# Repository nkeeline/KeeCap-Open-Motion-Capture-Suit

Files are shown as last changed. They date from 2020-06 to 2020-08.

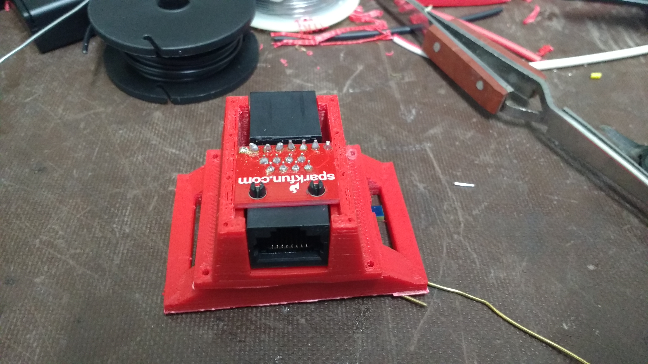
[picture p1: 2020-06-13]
Build Procedures/Sensor Build 2.jpg

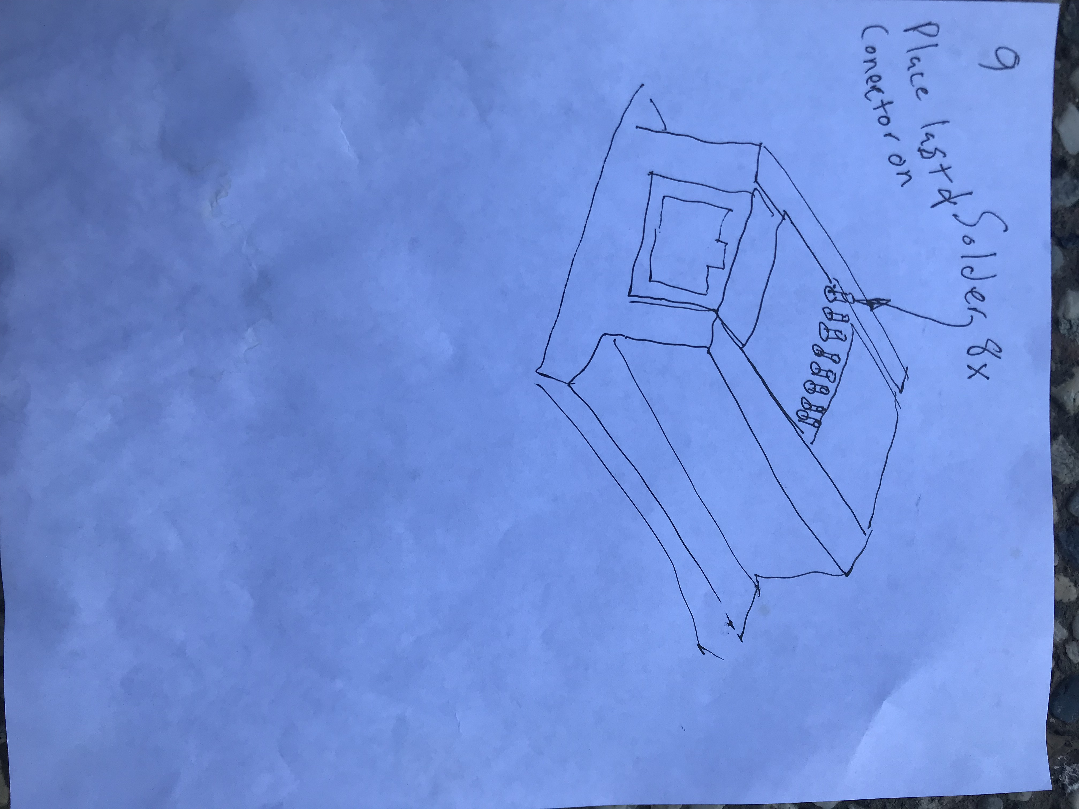
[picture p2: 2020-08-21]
Build Procedures/IMG_2739.JPG

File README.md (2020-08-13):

# KeeCap-Open-Motion-Capture-Suit
This is an arduino based open motion capture suit and all files necessary to build it.

If you are interested in this suit please watch these video tutorials:
Tutorial on how to use this code:

https://youtu.be/FGNmMZX0g_M

Tutorial on how the suit talks to Blender:

https://youtu.be/CypV9pPTCXo

If you want to test the PC only side without a suit you can use the latest python script from blender python dir in blender 2.83 and open the Move rig tester from the blender dir.

For the script to work in blender you MUST install PySerial into blender watch the second tutorial above to see how.

# This folder...

The suit bom.ods in the root contains all part numbers and prices for the components to buy the suit.  Open the file in libre office calc.  Most of the parts listed are from digikey.com, for example the imu board is this:
https://www.digikey.com/product-detail/en/microchip-technology/ATBNO055-XPRO/ATBNO055-XPRO-ND/5230918

# Arduino Code

This directory contains all of the code to put on the Arduino Mega 2560 in the suit.  It also contains the libraries the code uses you will need to place in your aruino libraries folder for the .ino file to compile.

# Blender Files

This contains the blender 2.83 files to export stl files necessary to 3d print the suit and a Move Rig.blend file with a character in it to map the motion captures to.

# Blender Python 

Contains a copy of the .py files for the addon to run in blender to import files from the suit.

# Build Procedures

This is the work instructions step by step for building the suit.

# Captures

Here are some sample captures taken during development and on set with sample videos of the capture process.

# Schematics Diagrams

These are the fritzing schematics and diagrams for the wiring of the suite to get an overview of how it's wired.

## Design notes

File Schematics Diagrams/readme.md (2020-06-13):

This folder contains all of the schematics and diagrams for building the suit

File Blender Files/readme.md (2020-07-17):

# Move Rig.blend
open this file and use it with the python script to apply poses to the rig in the blend file.  The sensors on the rig can be tweaked prior to applying a pose to adjust for off kilter sensors during the acquisition.

# You must install PySerial into blender python for the scripts to work!
for instructions on how to install it watch this tutorial:
https://www.youtube.com/watch?v=CypV9pPTCXo

# Waist and Arfuino and Accel Case blend files
These files contain all of the 3d printable models to create the suit.

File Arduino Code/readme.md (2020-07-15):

This folder contains all of the arduino code for putting in the arduino for the motion capture suit.

Unpack the MotionCaptureArduinoLibraries.zip into your Arduino Libraries folder.  then open the INO file and upload it into your Arduino Mega.

# Ignore Everything Below!!!! I tried to install all these from the web recently and the current libraries are no longer compatible with the code!!!  I packed up the libraries that work into a zip and included it in the repo so future generations will always be able to build the code.

To run the above code you need to put the following libraries into your arduino environment:

# Adafruit Unified BNO055 Driver (AHRS/Orientation) #

https://github.com/adafruit/Adafruit_Sensor

download the files from the above link and unpack the Adafruit_Sensor-Master folder into your Arduino/libraries folder.  Delete the -master from the folder name.

https://github.com/adafruit/Adafruit_BNO055

download the files from the above link and unpack the Adafruit_Sensor-Master folder into your Arduino/libraries folder.  Delete the -master from the folder name.

# Adafruit Data logging shield

for more information on the shield view this: https://learn.adafruit.com/adafruit-data-logger-shield/overview

use the above link to install the sd card and real time clock libraries, but in short download this:
https://github.com/adafruit/SD/archive/master.zip

download the files from the above link and unpack the SD-Master folder into your Arduino/libraries folder.  Delete the -master from the folder name.

also download this:

https://github.com/adafruit/RTClib

download the files from the above link and unpack the RTClib-Master folder into your Arduino/libraries folder.  Delete the -master from the folder name.

# Liquid Menu and LIquid Crystal from here:
https://github.com/arduino-libraries/LiquidCrystal
download the files from the above link and unpack the LiquidCrystal-Master folder into your Arduino/libraries folder.  Delete the -master from the folder name.

download the files from the above link and unpack the LiquidCristal-Master folder into your Arduino/libraries folder.  Delete the -master from the folder name.

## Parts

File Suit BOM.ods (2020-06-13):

Index | Quantity | Part Number | Description | Customer Reference | Available Quantity | Backorder Quantity | Unit Price USD | Extended Price USD
Chest BOM
1 | 1 | 1050-1018-ND | BOARD MCU MEGA2560 |  | 1 | 0 | $38.50 | $38.50
2 | 2 | ATBNO055-XPRO-ND | BNO055 XPLAINED PRO EVAL KIT |  | 1 | 0 | $21.43 | $21.43
3 | 1 | 1528-1044-ND | ASSEMBLED DATA LOGGING SHIELD |  | 1 | 0 | $13.95 | $13.95
4 | 2 | 1528-1363-ND | TCA9548A I2C MULTIPLEXER BOARD |  | 1 | 0 | $6.95 | $6.95
5 | 10 | 1568-1097-ND | RJ45 BREAKOUT |  | 4 | 0 | $0.95 | $3.80
6 | 10 | 609-1046-ND | CONN MOD JACK 8P8C R/A UNSHLD |  | 4 | 0 | $0.56 | $2.25
7 | 4 | EG2015-ND | SWITCH PUSH SPST-NO 3A 125V |  | 1 | 0 | $1.21 | $1.21
8 |  | EG2011-ND | SWITCH PUSH SPST-NO 3A 125V |  | 1 |  | $1.21 | $1.21
9 |  | amazon:https://www.amazon.com/dp/B071XP6PPT/ref=sspa_dk_detail_2?psc=1 | FICBOX IIC/I2C 1602 Serial 5V Blue Backlight LCD Display For Arduino 2560 UNO AVR |  | 1 |  | $9.99 | $9.99
Waist BOM
1 | 2 | 1528-1363-ND | TCA9548A I2C MULTIPLEXER BOARD |  | 1 | 0 | $6.95 | $6.95
2 | 10 | 1568-1097-ND | RJ45 BREAKOUT |  | 3 | 0 | $0.95 | $2.85
3 | 10 | 609-1046-ND | CONN MOD JACK 8P8C R/A UNSHLD |  | 3 | 0 | $0.56 | $1.69
4 | 2 | ATBNO055-XPRO-ND | BNO055 XPLAINED PRO EVAL KIT |  | 1 | 0 | $21.43 | $21.43
5 |  | 1528-1430-ND | BREAKOUT BOARD LM3671 3.3V |  | 1 | 0 | $4.95 | $4.95
Full Suit Sensors BOM
1 | 10 | 1568-1097-ND | RJ45 BREAKOUT |  | 20 | 0 | $0.95 | $19.00
2 | 10 | 609-1046-ND | CONN MOD JACK 8P8C R/A UNSHLD |  | 20 | 0 | $0.56 | $11.26
3 | 2 | ATBNO055-XPRO-ND | BNO055 XPLAINED PRO EVAL KIT |  | 13 | 0 | $21.43 | $278.59
 |  |  |  |  |  |  | total: | $446.01
6 | 1 | 1568-1357-ND | HOOK-UP WIRE ASSORT SOLID 22AWG |  |  | 0 | $16.95 | $16.95
 |  | https://www.amazon.com/IWISS-Terminal-Ratchet-AWG28-18-0-1-1-0MM%C2%B2/dp/B017JU20Z6?s=aps
 |  | https://www.amazon.com/QLOUNI-Housing-Connector-Adaptor-Assortment/dp/B0774NMT1S
5 |  | 1528-1430-ND | BREAKOUT BOARD LM3671 3.3V |  | 1 | 0 | $4.95 | $4.95
1 | 2 | 1528-1363-ND | TCA9548A I2C MULTIPLEXER BOARD |  | 1 | 0 | $6.95 | $6.95
 |  | 1568-1358-ND | HOOK-UP WIRE ASSORT STRAND 22AWG |  | 1 |  | $16.95 | $16.95
 |  | 1568-1357-ND | HOOK-UP WIRE ASSORT SOLID 22AWG |  | 1 |  | $16.95 | $16.95

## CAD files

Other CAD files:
Blender Files/Accel Case 2nd try.blend

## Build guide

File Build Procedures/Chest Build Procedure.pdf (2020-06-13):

### Chest Build Procedure

### Names of Boards refer to this page to get the

names of the components.

Mega 2560 (the brain)

Adafruit I2C multiplexer
board.

IMU (inertial
measurement Unit)

Adafruitt Data Logging
Shield (SD card board)

### During build make sure all solder joints connect the pin to the hole (no gold rings showing). Hold the iron for a second or two on the pin to let the solder wick into the shaft with the pin in it)

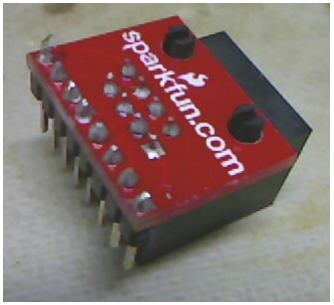
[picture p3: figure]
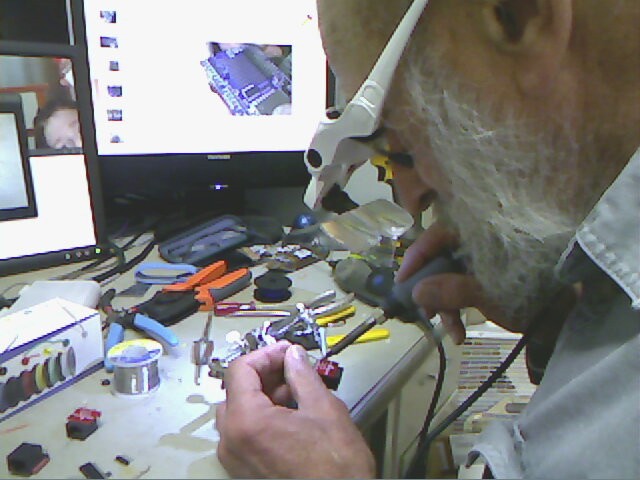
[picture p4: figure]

Print Out Chest Base

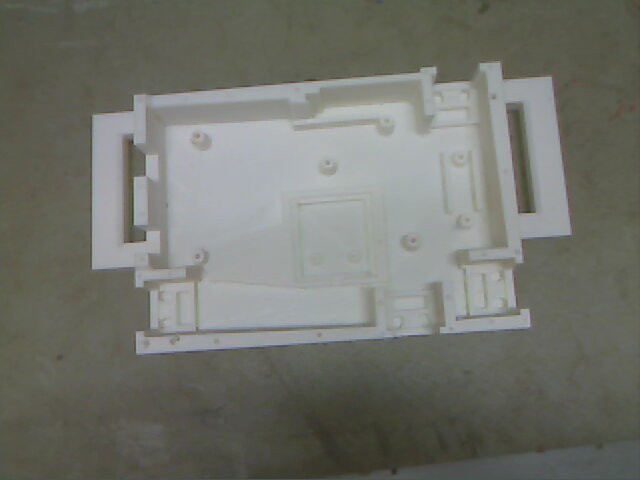
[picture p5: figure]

Don’t forget the
female header
on the center
pins.

Install all headers necessary to solder to the Adafruit Data Logging (sd card) shield into the Mega 2560 board.

Add the shield on to the 2560 and solder all of the headers in.

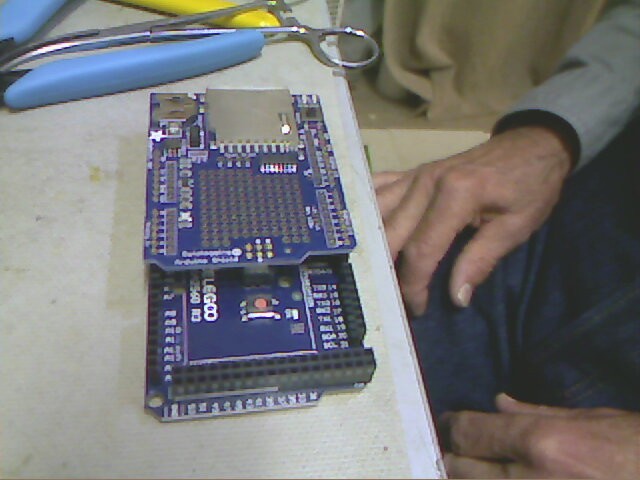
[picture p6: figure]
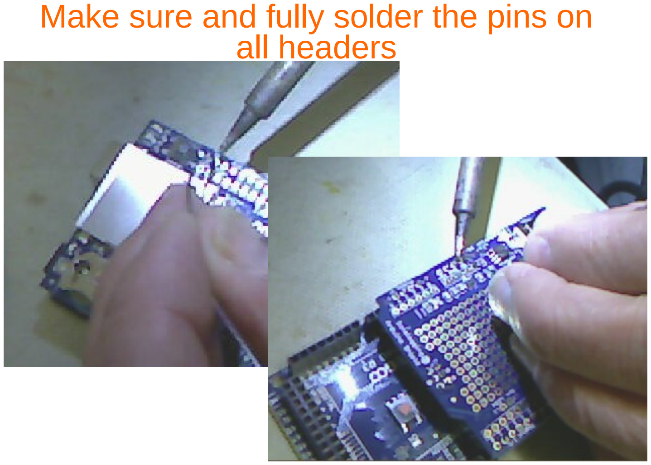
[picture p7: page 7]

Make sure and fully solder the pins on all headers

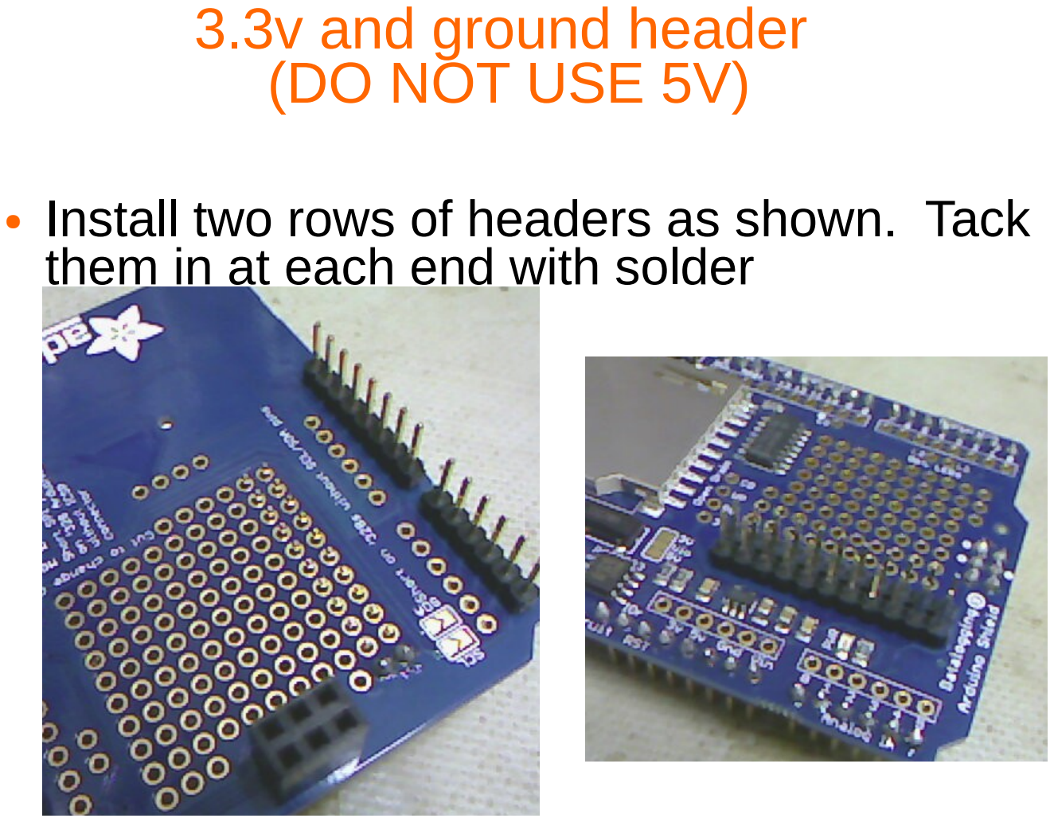
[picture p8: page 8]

3.3v and ground header
(DO NOT USE 5V)
- Install two rows of headers as shown. Tack them in at each end with solder

Solder a Red Wire up through the 3V hole and connect it to the row of header that is closest to the center of the board.

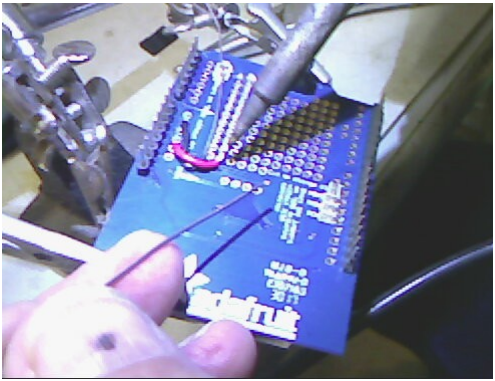
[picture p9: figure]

Connect a black wire through the Gnd hole and connect it to the row of pins closest to the edge

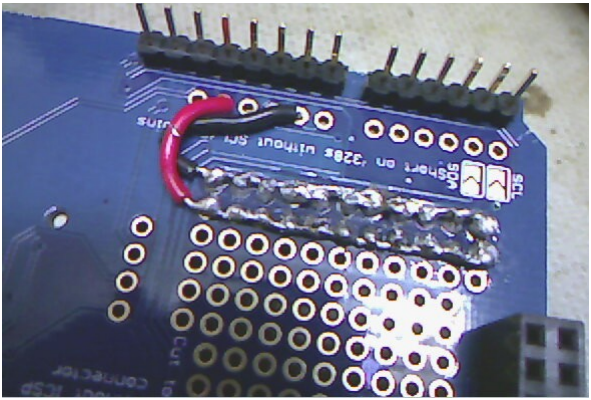
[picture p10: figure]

This is what the header looks like when done.

Solder a Header on pins 0-5 and Solder a wire on the topside from L1 to pin 6 on the Data Logging shield

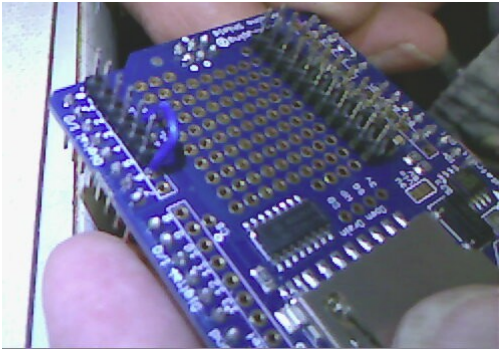
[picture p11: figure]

Put header on pins Sclk through 8 and Solder a wire on the topside from L2 to pin 7 on the Data Logging shield

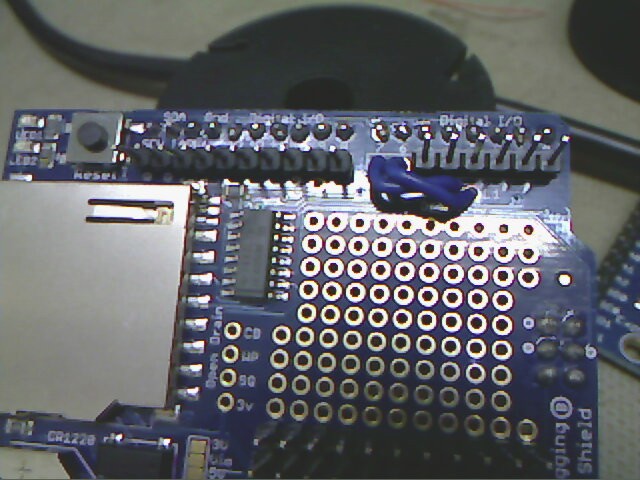
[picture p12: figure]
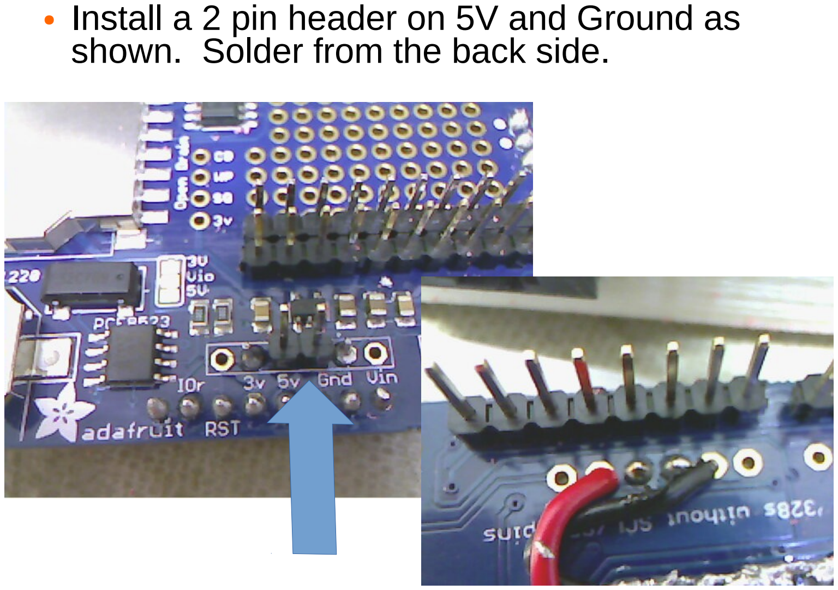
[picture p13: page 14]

- Install a 2 pin header on 5V and Ground as shown. Solder from the back side.

Clip all pins on the IMU flush except 11,12,19 and 20.

Solder four stranded wires 4-5 inches long:
red-20,black-19,white-12,yellow 11.

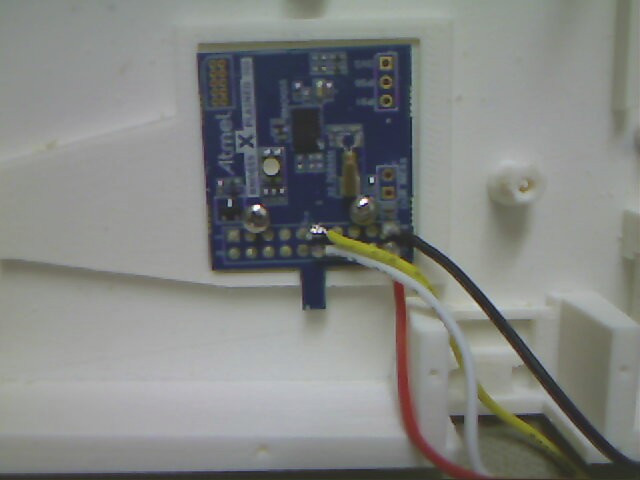
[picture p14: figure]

Install Arduino Mega 2560

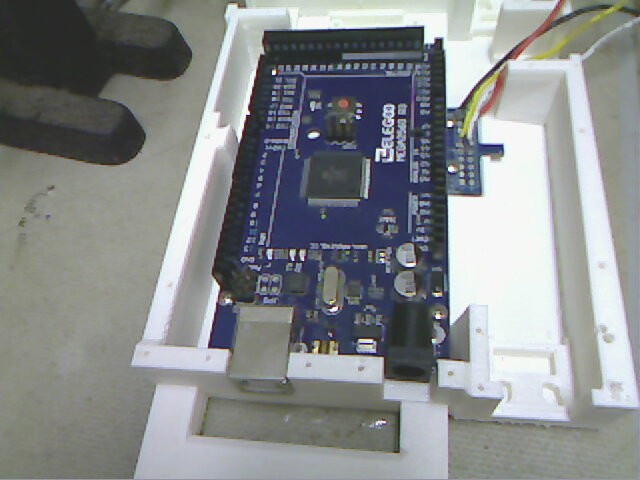
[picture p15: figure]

Install Data Logging Shield on to Mega 2560 (line up male females as shown)

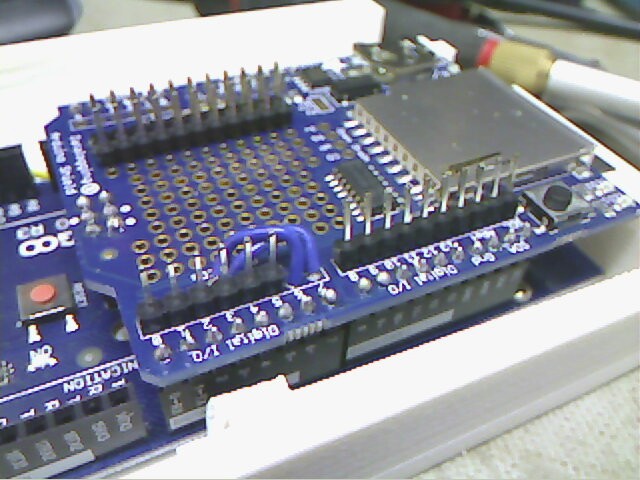
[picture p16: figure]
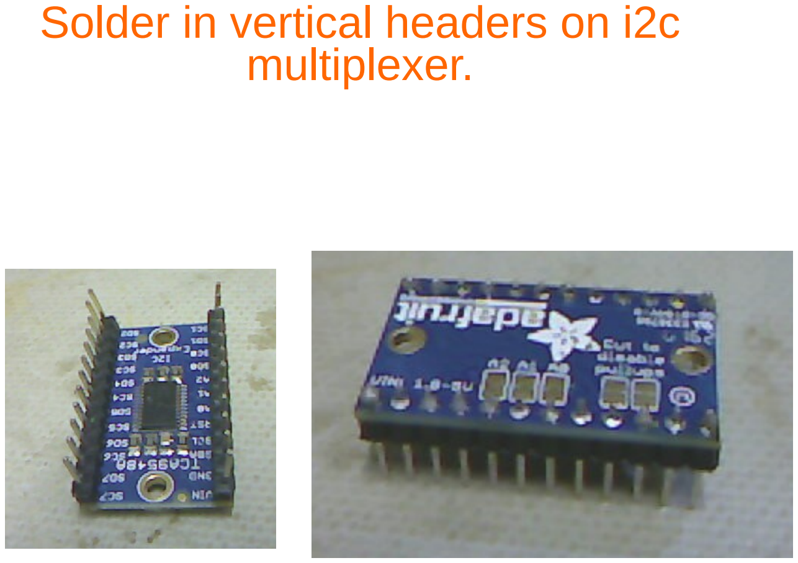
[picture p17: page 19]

Solder in vertical headers on i2c multiplexer.

Install I2C Multiplexer into assembly as shown (note orientation).

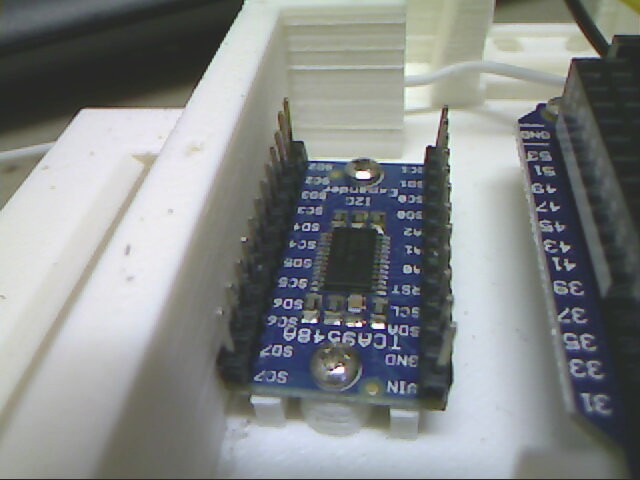
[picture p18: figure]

Make four Ethernets with headers on them as shown

Epoxy the four Ethernets into their locations in the assembly
- Start a Harness On the Upper Left Arm Connector. Create two wires for power and four wires for SDA and SCLK.

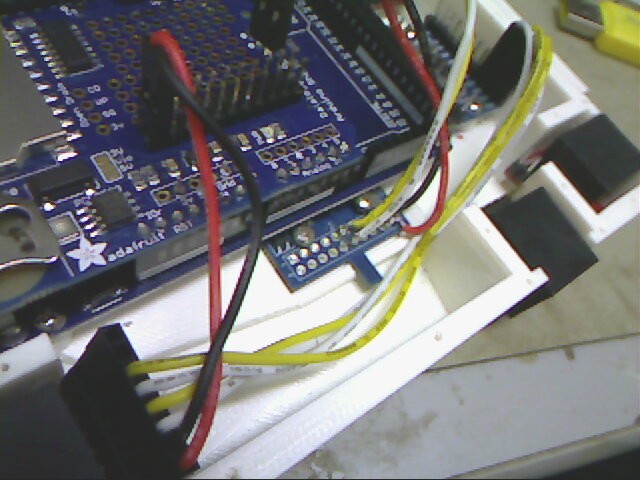
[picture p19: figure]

Finish the Upper Left Harness by connecting it to SD2, SC2, SD3, and SC3 as shown
- Pin 3 white of the Ethernet goes to SC2,
- Pin 4 yellow goes to SD2,
- Pin 5 white goes to SC3
and
- pin 6 yellow goes to SD3.

Put two two pin terminals on the wires coming off of the IMU that we put in

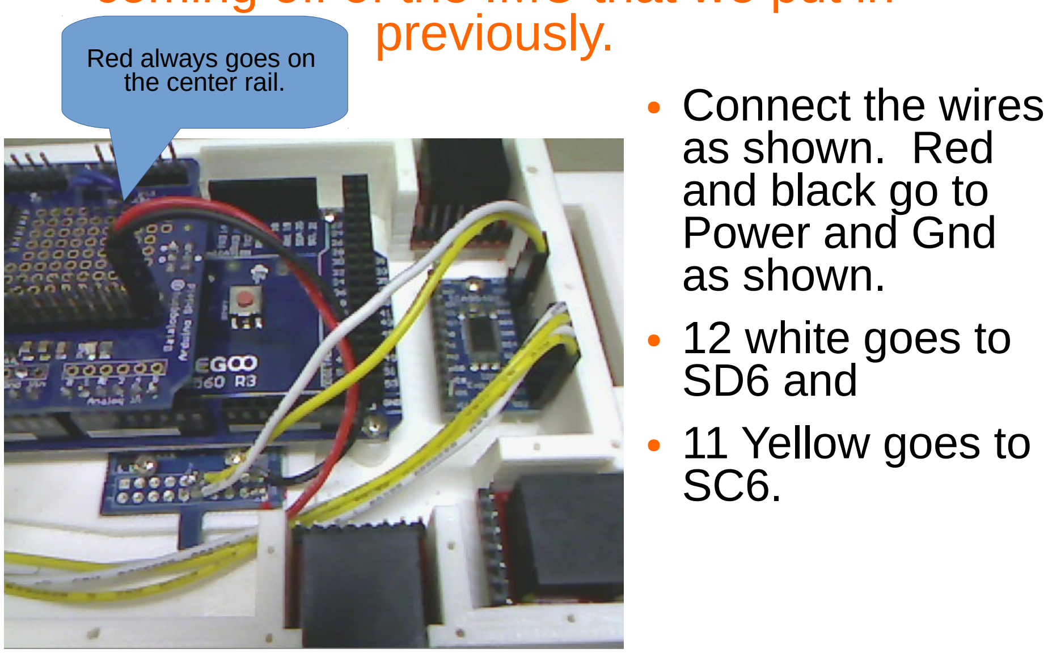
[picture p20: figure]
previously.; ● Connect the wires as shown. Red and black go to Power and Gnd as shown. ● 12 white goes to SD6 and ● 11 Yellow goes to SC6.; Red always goes on the center rail.

Create the head harness

- Create a four pin
header that
connects to the
head ethernet as
shown. Pins
1(power) and
2(gnd) go to the
power header on
the data logging
shield. Pin 3 white
goes to SC4 and
Pin 4 yellow goes
to SD4. (as shown

- Wire up the Right Arm. Put a Red on Pin 1 and Black on Pin 2. Place a two pin header on them and connect them to the power rail header on the data logging shield.

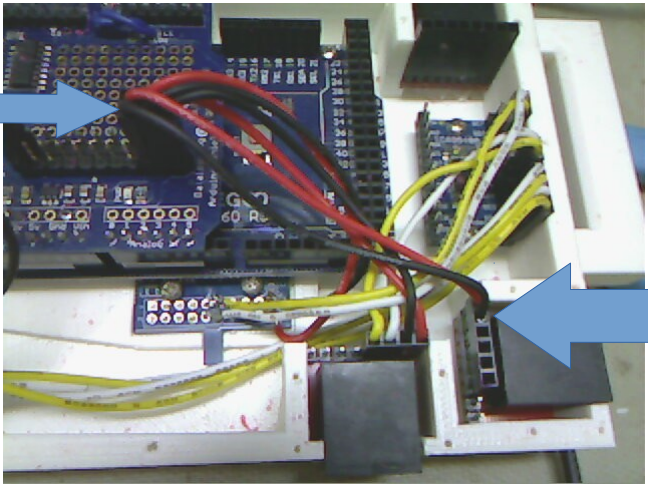
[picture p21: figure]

- Pin 3 White goes to SC0.
- Pin 4 Yellow goes to SD0
- Pin 5 White goes to SC1
- Pin 6 Yellow goes to SD1

- Create a harness for the waist.
- Pin1 Red goes to 3.3v header.
- Pin2 Black goes to 3.3v ground header
- Pin 7 Red goes to 5v on two pin 5V Gnd header
- Pin 8 Black goes to Gnd on two pin 5V Gnd Header

Pin 8 Pin 1

5V Gnd header

3

3. v

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
- Wire the waist power as shown.

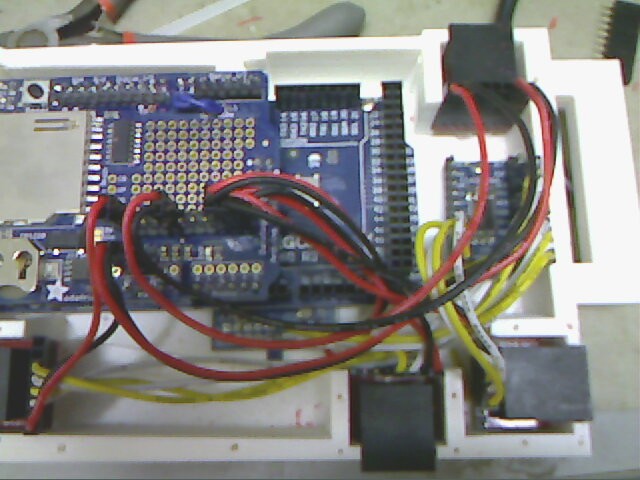
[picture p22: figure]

- Install two wires On the waist connector.
- Pin 3 White goes to SC7
- Pin 4 Yellow goes to SD7

- Create a two pin to two pin harness with one white wire and one yellow wire.
- SDA – white from the Data logging shield goes to SDA white on the I2c Multiplexer.
- SCL – Yellow from the data logging shield goes to SCL yellow on the i2c muliplexer

- Create a 2 pin harness to power the I2C muliplexer.
- Red Wire Vin from the I2C muliplexer goes to the 3.3V common header on the Data logging Shield.
- Black Wire Ground should go from Gnd on the I2C muliplexer to the ground common header on the Data Logging Shield.

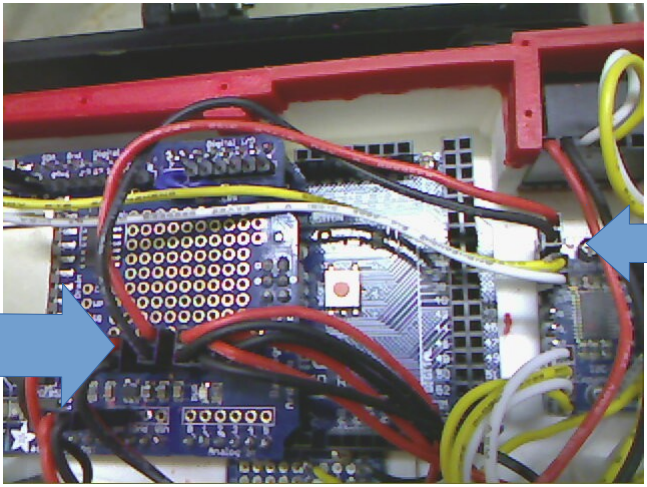
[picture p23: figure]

- The LCD display in the lid has a 4 pin male header. Create four wires, with a male and female contact at each end:
- Pin 1 of LCD GND: Female contact Black wire goes to male contact marked GND on header on Mega 2560 (see below)
- Pin 2 of LCD VCC: Female contact Red Wire goes to male contact marked 5V on header on Mega2560 (see below)
- Pin 3 of LCD SDA: Female contact Yellow wire goes to pin 20 marked SDA
- Pin 4 of LCD SCL: female contact white wire goes to pin 21 marked SCL on the mega 2560. Male Contacts Pin 3 and 4 can go into a two pin housing to connect.

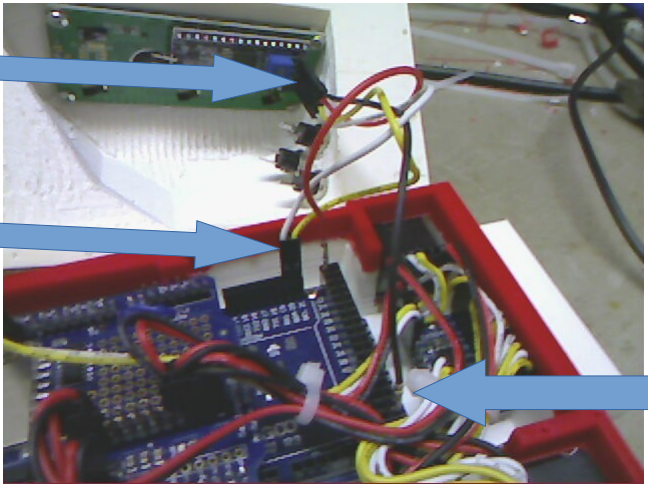
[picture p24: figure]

- Make three black wires and solder each to a side of each of the switches. Take the other end to a 3 pin housing and connect it to the ground side of the 3.3V common power header (as shown)

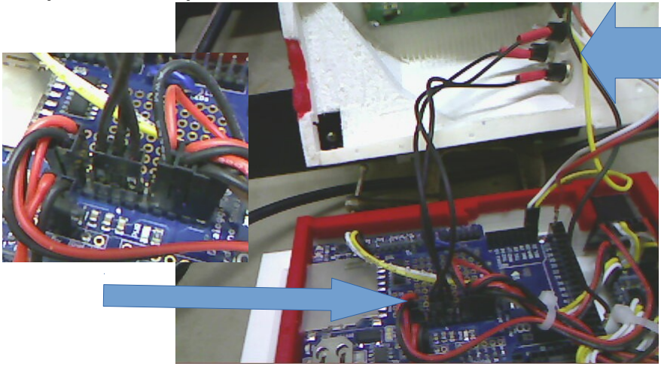
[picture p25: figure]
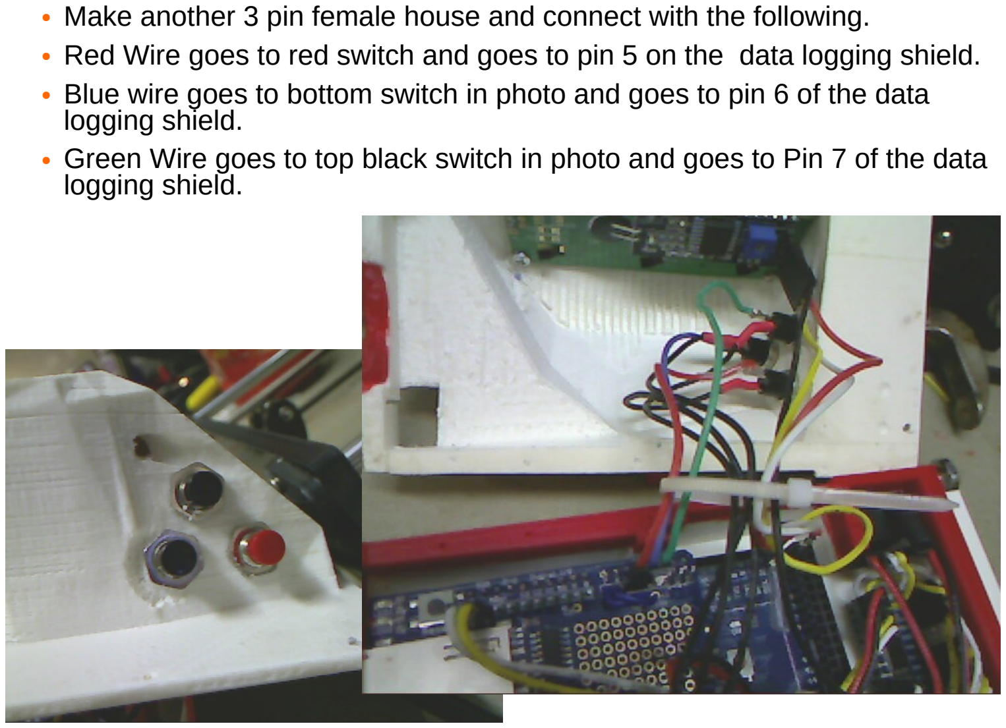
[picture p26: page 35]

- Make another 3 pin female house and connect with the following.
- Red Wire goes to red switch and goes to pin 5 on the data logging shield.
- Blue wire goes to bottom switch in photo and goes to pin 6 of the data logging shield.
- Green Wire goes to top black switch in photo and goes to Pin 7 of the data logging shield.

It‘s done!!!

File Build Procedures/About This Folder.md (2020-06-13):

This folder contains the build procedures for the various parts of the suit.

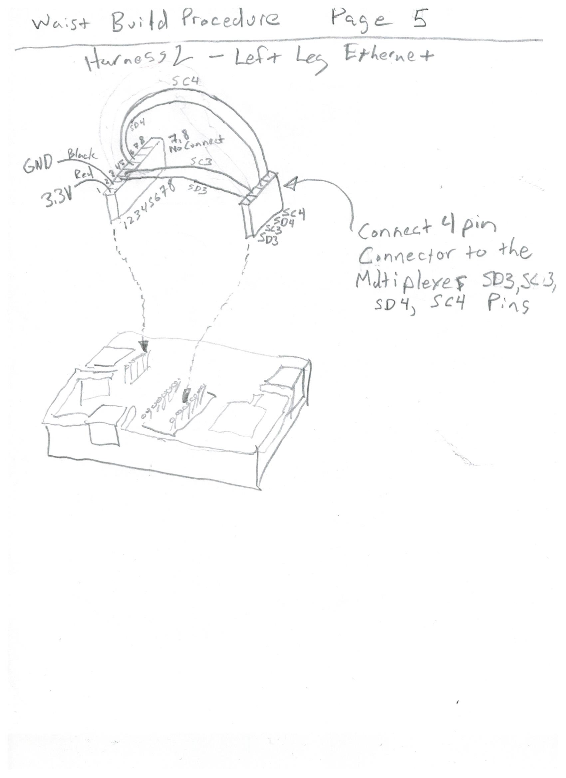
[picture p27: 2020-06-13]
Build Procedures/Waist Build Procedure Pg5.jpg

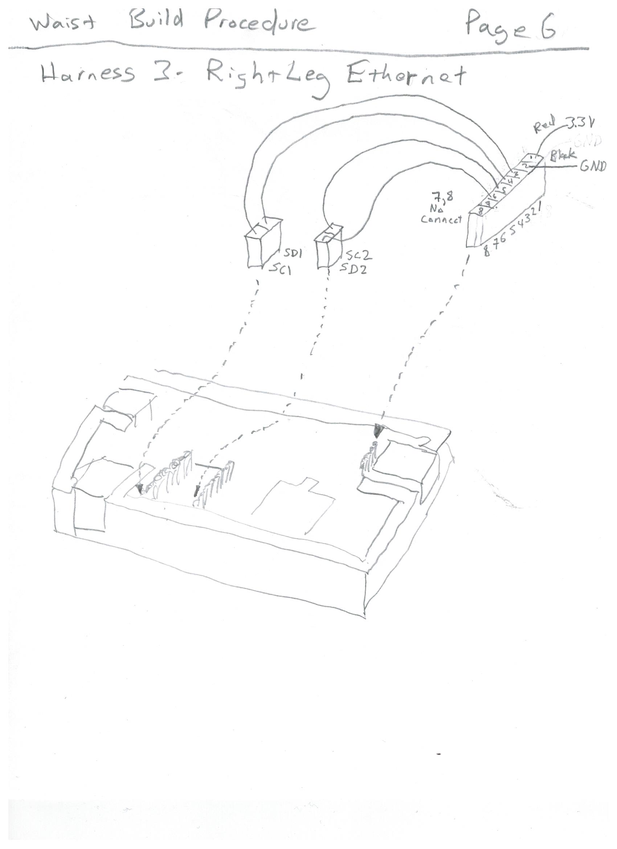
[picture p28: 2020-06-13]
Build Procedures/Waist Build Procedure Pg6.jpg

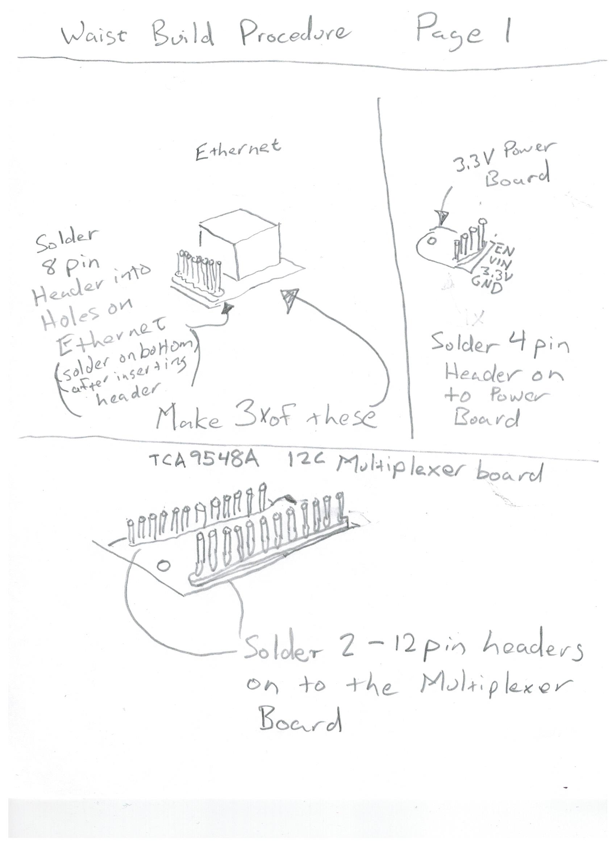
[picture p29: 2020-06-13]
Build Procedures/Waist Build Procedure Pg1.jpg

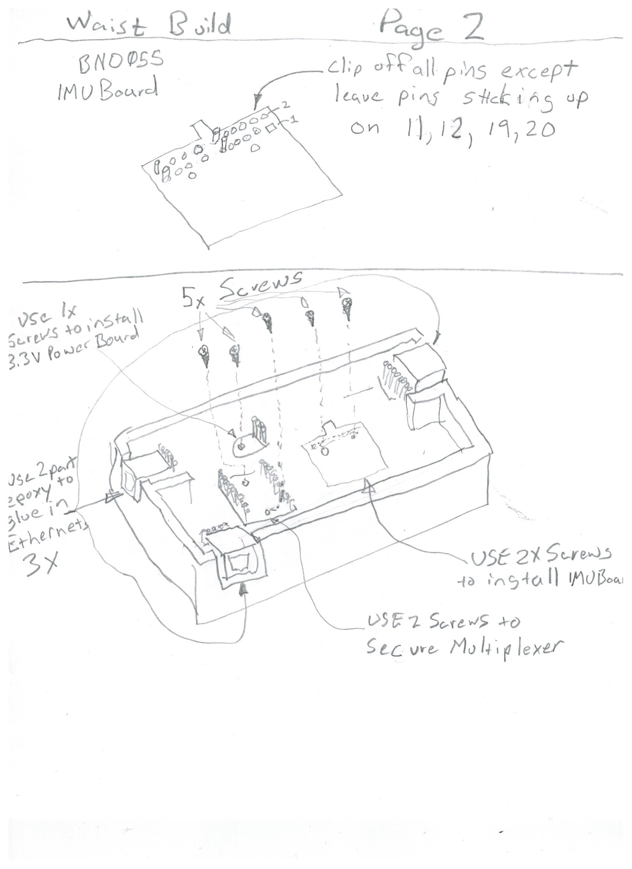
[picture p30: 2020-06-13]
Build Procedures/Waist Build Procedure Pg2.jpg

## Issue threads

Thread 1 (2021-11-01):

Include .STL files for the 3d printing

ccmitchellusa, 2021-11-01:
Could you add .STL files that were used for 3d printing the parts, exporting the .blender files to STL and then running through a slicer like ICE has issues.  We're new to the whole process and may be missing a step, but it's not clear as to how to get good STL files from the blender's.

ccmitchellusa, 2021-11-01:
After re-watching the overview video and inspecting the .blender files further, it looks like there are multiple parts that each need to be exported as individual selections to .stl.  One needs to figure out how many of each embedded part needs to be printed, since the number of parts will vary for a full suit.

Closed 2021-11-01.

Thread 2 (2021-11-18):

Chest build procedures need to be updated for newest Adafruit Datashield.

ccmitchellusa, 2021-11-18:
The latest Adafruit Datashield https://learn.adafruit.com/adafruit-data-logger-shield/shield-overview (see Prototyping Area section) has built-in voltage and gnd rails in the prototyping area that are reversed from the rail configuration used in the suit build procedures.  GND rail is toward the center of the board.  This means the wiring in that step of the chest build procedures needs to be reversed otherwise it creates a short and the SD CardInfo test will fail.  All other steps later in the chest build procedures that connect to the rails need to have red/black flipped.

ccmitchellusa, 2021-11-18:
This is how it needs to be wired to work correctly.
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

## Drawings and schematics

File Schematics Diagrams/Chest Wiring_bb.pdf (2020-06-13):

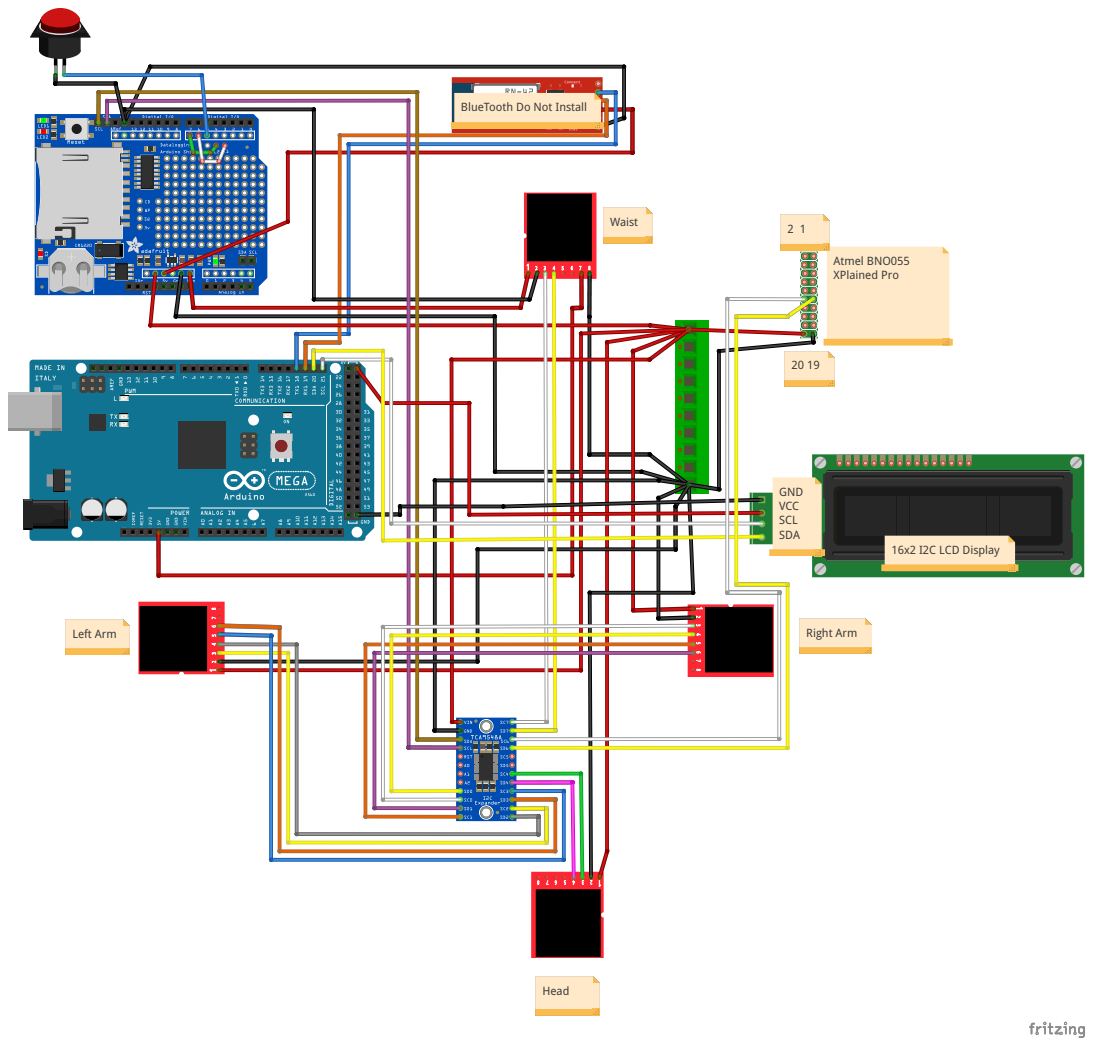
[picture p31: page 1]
Head; Right Arm; 16x2 I2C LCD Display; Left Arm; Waist; GND VCC SCL SDA; Atmel BNO055 XPlained Pro

BlueTooth Do Not Install

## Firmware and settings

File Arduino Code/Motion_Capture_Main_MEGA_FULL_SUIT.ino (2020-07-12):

#include <Wire.h>
#include <Adafruit_Sensor.h>
#include <Adafruit_BNO055.h>
#include <utility/imumaths.h>
// include the SD library:
#include <SPI.h>
#include <SD.h>
#include "RTClib.h"
#include <LiquidCrystal_I2C.h>


#define NAMECHEST "chest"
#define NAMEBICEP_R "upper_arm.R"
#define NAMEFOREARM_R "forearm.R"
#define NAMEHAND_R "hand.R"
#define NAMEBICEP_L "upper_arm.L"
#define NAMEFOREARM_L "forearm.L"
#define NAMEHAND_L "hand.L"
#define NAMEHEAD "head"
#define NAMEWAIST "spine"
#define NAMETHIGH_R "thigh.R"
#define NAMETHIGH_L "thigh.L"
#define NAMEKNEE_R "shin.R"
#define NAMEKNEE_L "shin.L"
#define NAMEFOOT_R "foot.R"
#define NAMEFOOT_L "foot.L"
/* This driver reads raw data from the BNO055

   Connections
   ===========
   Connect SCL to analog 5
   Connect SDA to analog 4
   Connect VDD to 3.3V DC
   Connect GROUND to common ground

   History
   =======
   2015/MAR/03  - First release (KTOWN)
*/
/**************************************************
 * VERSION
 *************************************************/
  float Version = 1.01;
  String VersionString = String(Version,2);
/**************************************************
 *************************************************/

  
// all of the types of sensors we will have.
typedef enum 
{
      CHEST,                                       
      BICEP_R,                                    
      FOREARM_R,                                     
      HAND_R,                                      
      BICEP_L,                                      
      FOREARM_L,                                    
      HAND_L,                                    
      HEAD,                                       
      WAIST,                                       
      THIGH_R,                                    
      KNEE_R,                                     
      FOOT_R,                                     
      THIGH_L,                                    
      KNEE_L,                                    
      FOOT_L                                     
} sensor_id;
 
/* Set the delay between fresh samples */
#define BNO055_SAMPLERATE_DELAY_MS (100)

/*
syntax for this is first item is 
device id, not sure what this is, 
device addres either 0x29 or 0x28 for BNO055
mux 1 port:the sensor is on for the mux (unused if next value is not -1)
mux 2 port is the port on the second mux daisy chained off of the first mux at a port defined in the header file.

*/
/*Adafruit_BNO055::Adafruit_BNO055(int32_t sensorID, uint8_t address, int32_t mux1port, int32_t mux2port)*/
Adafruit_BNO055 chest = Adafruit_BNO055(-1,BNO055_ADDRESS_B, 6, -1);
bool chestPresent;

/* Head */
Adafruit_BNO055 head = Adafruit_BNO055(-1,BNO055_ADDRESS_A, 4, -1);
bool headPresent;

/* Right ARm*/
Adafruit_BNO055 forearmR = Adafruit_BNO055(-1,BNO055_ADDRESS_A, 0, -1);
bool forearmRPresent;
Adafruit_BNO055 bicepR = Adafruit_BNO055(-1,BNO055_ADDRESS_B, 0, -1);
bool bicepRPresent;
Adafruit_BNO055 handR = Adafruit_BNO055(-1,BNO055_ADDRESS_B, 1, -1);
bool handRPresent;

/* Left ARm*/
Adafruit_BNO055 forearmL = Adafruit_BNO055(-1,BNO055_ADDRESS_A, 2, -1);
bool forearmLPresent;
Adafruit_BNO055 bicepL = Adafruit_BNO055(-1,BNO055_ADDRESS_B, 2, -1);
bool bicepLPresent;
Adafruit_BNO055 handL = Adafruit_BNO055(-1,BNO055_ADDRESS_B, 3, -1);
bool handLPresent;

/* waist */
Adafruit_BNO055 waist = Adafruit_BNO055(-1,BNO055_ADDRESS_B, -1, 0);
bool waistPresent;


/* Right Leg*/
Adafruit_BNO055 thighR = Adafruit_BNO055(-1,BNO055_ADDRESS_A, -1, 1);
bool thighRPresent;
Adafruit_BNO055 kneeR = Adafruit_BNO055(-1,BNO055_ADDRESS_B, -1, 1);
bool kneeRPresent;
Adafruit_BNO055 footR = Adafruit_BNO055(-1,BNO055_ADDRESS_B, -1, 2);
bool footRPresent;


/* Left Leg*/
Adafruit_BNO055 thighL = Adafruit_BNO055(-1,BNO055_ADDRESS_A, -1, 3);
bool thighLPresent;
Adafruit_BNO055 kneeL = Adafruit_BNO055(-1,BNO055_ADDRESS_B, -1, 3);
bool kneeLPresent;
Adafruit_BNO055 footL = Adafruit_BNO055(-1,BNO055_ADDRESS_B, -1, 4);
bool footLPresent;

bool QuatMode;
int TakeNumber = 1;
bool IMUsInitialized = false;
bool IMUsCalibrated = false;

// set up variables using the SD utility library functions:
Sd2Card card;
SdVolume volume;
SdFile root;
const int chipSelect = 10;

// real time clock.
RTC_PCF8523 rtc;
char daysOfTheWeek[7][12] = {"Sunday", "Monday", "Tuesday", "Wednesday", "Thursday", "Friday", "Saturday"};

bool sdCardPresentandIntialized = false;
const int buttonPin = 5;     // the number of the pushbutton pin
//LEDs
const int ledGreenPin =  7;// the number of the LED pin
const int ledRedPin =  6;// the number of the LED pin
unsigned long CaptureDelay = 0;

//LCD Display
#define LCD_DISPLAY_ADDR 0x27
LiquidCrystal_I2C lcd(0x27, 16, 2);
bool DisplayFound = false;

/**************************************************************************/
/*
    LED Function- all Good
*/
/**************************************************************************/
bool CheckForLCDConnect(void)
{
  byte error;

    Wire.beginTransmission(LCD_DISPLAY_ADDR);
    error = Wire.endTransmission();     // stop transmitting
    if (error == 0)
    {
      DisplayFound = true;
      lcd.begin();
      Serial.println("LCD Display Found at 0x27...");
    } else
    {
      Serial.println("No LCD Display found...");
    }
  
}
void ClearRowOfDisplay(int RowNum){
  if(RowNum == 1)
  {
    lcd.setCursor(0, 0);
    lcd.print("                ");
  } else
  {
    lcd.setCursor(0, 1);
    lcd.print("                ");
  }
}
void PrintLCDLine1(String c)
{
  if(DisplayFound)
  {
    ClearRowOfDisplay(1);
    lcd.setCursor(0, 0);
    lcd.print(c);
  }
}
void PrintLCDLine2(String c)
{
  if(DisplayFound)
  {
    ClearRowOfDisplay(2);
    lcd.setCursor(0, 1);
    lcd.print(c);
  }
}
/**************************************************************************/
/*
    LED Function- all Good
*/
/**************************************************************************/
void SetupLEDs(){
  pinMode(ledGreenPin, OUTPUT);
  pinMode(ledRedPin, OUTPUT);
}
void StatusAllGood(){
  digitalWrite(ledGreenPin, HIGH);
  digitalWrite(ledRedPin, LOW);
}
void Busy(){
  digitalWrite(ledGreenPin, !digitalRead(ledGreenPin));
  digitalWrite(ledRedPin, LOW);
}
void Recording(){
  digitalWrite(ledRedPin, !digitalRead(ledRedPin));
  digitalWrite(ledGreenPin, LOW);
}
void StatusAllBad(){
  digitalWrite(ledGreenPin, LOW);
  digitalWrite(ledRedPin, HIGH);
}
/**************************************************************************/
/*
    Set Capture Speed
*/
/**************************************************************************/
unsigned long SetSpeed( unsigned long CurrentDelay ){
  unsigned long SpeedDelayOut = 0;
  long int userInput;
  
  Serial.print("Current Delay is Set To: ");
  Serial.println(CurrentDelay, DEC);
  Serial.println("Please Enter the speed you want to capture at:");
  Serial.println("0 As Fast As Possible");  
  Serial.println("1 is Super Fast");        
  Serial.println("2 Fast");             
  Serial.println("3 Medium");              
  Serial.println("4 Slow");              
  Serial.println("5 Super Slow");   
    while (Serial.available()==0)  { }
  userInput = Serial.parseInt();

  switch(userInput){
  case 0:
    SpeedDelayOut = 0;
    break;
  case 1:
    SpeedDelayOut = 10;
    break;
  case 2:
    SpeedDelayOut = 50;
    break;
  case 3:
    SpeedDelayOut = 100;
    break;
  case 4:
    SpeedDelayOut = 200;
    break;
  case 5:
    SpeedDelayOut = 500;
    break;
  default:
    SpeedDelayOut = BNO055_SAMPLERATE_DELAY_MS;

  }   
  Serial.print("Delay is Set To: ");
  Serial.println(SpeedDelayOut, DEC);
  return SpeedDelayOut;
}
  
/**************************************************************************/
/*
    Set the Clock
*/
/**************************************************************************/
void GetTimeFromUserAndSet(){
  long int userYear; 
  long int userMonth = 1; 
  long int userDay = 21; 
  long int userHour = 8; 
  long int userMinute = 30; 
  long int userSecond = 0; 
  DateTime now = rtc.now();

  Serial.print("Please Enter The Year: (i.e. ");
  Serial.print(now.year(), DEC);
  Serial.println(")");        //Prompt User for input
    while (Serial.available()==0)  { }
    userYear = Serial.parseInt();

  Serial.print("Please Enter The Month: (i.e. ");
  Serial.print(now.month(), DEC);
  Serial.println(")");        //Prompt User for input
    while (Serial.available()==0)  { }
    userMonth = Serial.parseInt();
    
  Serial.print("Please Enter The Day: (i.e. ");
  Serial.print(now.day(), DEC);
  Serial.println(")");        //Prompt User for input
    while (Serial.available()==0)  { }
    userDay = Serial.parseInt();
    
  Serial.print("Please Enter The Hour: (i.e. ");
  Serial.print(now.hour(), DEC);
  Serial.println(")");        //Prompt User for input
    while (Serial.available()==0)  { }
    userHour = Serial.parseInt();
    
  Serial.print("Please Enter The Minute: (i.e. ");
  Serial.print(now.minute(), DEC);
  Serial.println(")");        //Prompt User for input
    while (Serial.available()==0)  { }
    userMinute = Serial.parseInt();
    
  Serial.print("Please Enter The Second: (i.e. ");
  Serial.print(now.second(), DEC);
  Serial.println(")  When you press enter the time will be committed.");        //Prompt User for input
    while (Serial.available()==0)  { }
    userSecond = Serial.parseInt();

    
    rtc.adjust(DateTime(userYear,userMonth, userDay, userHour, userMinute, userSecond));
    
  Serial.println("Time Set To:" + GetTime());        //Prompt User for input
}
/**************************************************************************/
/*
    SDCard Info Display
*/
/**************************************************************************/
bool DetectAndDisplaySDCardInfo(){

  bool cardPassedInit = true;
  Serial.print("\nInitializing SD card...");
  Busy();
  // we'll use the initialization code from the utility libraries
  // since we're just testing if the card is working!
  if (!card.init(SPI_HALF_SPEED, chipSelect)) {
    Serial.println("initialization failed. Things to check:");
    Serial.println("* is a card inserted?");
    Serial.println("* is your wiring correct?");
    Serial.println("* did you change the chipSelect pin to match your shield or module?");
    cardPassedInit = false;
    StatusAllBad();
  } else {
    Serial.println("Wiring is correct and a card is present.");
    Busy();
  }

  if(cardPassedInit){
    // print the type of card
    Serial.print("\nCard type: ");
    switch (card.type()) {
      case SD_CARD_TYPE_SD1:
        Serial.println("SD1");
        break;
      case SD_CARD_TYPE_SD2:
        Serial.println("SD2");
        break;
      case SD_CARD_TYPE_SDHC:
        Serial.println("SDHC");
        break;
      default:
        Serial.println("Unknown");
    Busy();
    }
  
    // Now we will try to open the 'volume'/'partition' - it should be FAT16 or FAT32
    if (!volume.init(card)) {
      Serial.println("Could not find FAT16/FAT32 partition.\nMake sure you've formatted the card");
      cardPassedInit = false;
      return cardPassedInit;
      Busy();
    }
  
  
    // print the type and size of the first FAT-type volume
    uint32_t volumesize;
    Serial.print("\nVolume type is FAT");
    Serial.println(volume.fatType(), DEC);
    Serial.println();
    Busy();
  
    volumesize = volume.blocksPerCluster();    // clusters are collections of blocks
    volumesize *= volume.clusterCount();       // we'll have a lot of clusters
    volumesize *= 512;                            // SD card blocks are always 512 bytes
    Serial.print("Volume size (bytes): ");
    Serial.println(volumesize);
    Serial.print("Volume size (Kbytes): ");
    volumesize /= 1024;
    Serial.println(volumesize);
    Serial.print("Volume size (Mbytes): ");
    volumesize /= 1024;
    Serial.println(volumesize);
    Busy();
  
  
    Serial.println("\nFiles found on the card (name, date and size in bytes): ");
    root.openRoot(volume);
  
    // list all files in the card with date and size
    root.ls(LS_R | LS_DATE | LS_SIZE);
    Busy();
  }
  
  return cardPassedInit;
}
/**************************************************************************/
/*
    Get Time String
*/
/**************************************************************************/
String GetTime(){
  
    DateTime now = rtc.now();
    String TimeString = String(now.year(), DEC);
    TimeString += '/';
    TimeString += String(now.month(), DEC);
    TimeString += '/';
    TimeString += String(now.day(), DEC);
    TimeString += " (";
    TimeString += String(daysOfTheWeek[now.dayOfTheWeek()]);
    TimeString += ") ";
    TimeString += String(now.hour(), DEC);
    TimeString += ':';
    TimeString += String(now.minute(), DEC);
    TimeString += ':';
    TimeString += String(now.second(), DEC);
    return TimeString;
}
/**************************************************************************/
/*
    SDCard Init
*/
/**************************************************************************/
void initializeSDCardForDataLogging(){
  // see if the card is present and can be initialized:
  if (!SD.begin(chipSelect)) {
    Serial.println("Card failed, or not present");
    // don't do anything more:
    return;
  } else{
  sdCardPresentandIntialized = true;
  Serial.println("card initialized.");
  }
}
/**************************************************************************/
/*
    Get FileName for datalogging
*/
/**************************************************************************/
String DataLoggingName(){
    DateTime now = rtc.now();
    int filenum = 1;
    String FinalString = "";
    String Temp = String(now.year(), DEC);
    String TimeString = Temp.substring(Temp.length() -1);
    TimeString += String(now.month(), DEC);
    TimeString += String(now.day(), DEC);
    TimeString += "_";
    FinalString = TimeString + String(filenum, DEC) + ".TXT";
    while(SD.exists(FinalString)){
      filenum = filenum + 1;
      FinalString = TimeString + String(filenum, DEC) + ".TXT";
    }    
  return FinalString;
}
/**************************************************************************/
/*
    Print Line to File
*/
/**************************************************************************/
void PrintLine2File(String Line, File dataFile){
  if (dataFile) {
    dataFile.println(Line);
  }
}
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
void loop(void)
{
  unsigned long StartTime;
  unsigned long CurrentTime;
  int incomingByte = 0;
  bool ButtonPushed = false;
  String TimeLine = "";
  Serial.println("Spark MoCap Version: " + VersionString);
  Serial.println("Use the Keyboard to select the following options");
  Serial.println("e : enumerate I2C devices");
  Serial.println("i : Initialize Available Devices");
  Serial.println("r : read from device (press any key to stop)");
  Serial.println("s : Set Mux to Port Number you enter");
  Serial.println("q : Set output read to quaternion mode.");
  Serial.println("w : Set output read to euler mode.");
  Serial.println("t : Begin Take by starting T Pose Process");
  Serial.println("c : calibrate Sensor Process");
  Serial.println("d : SD Card Detect and Display Results.");
  Serial.println("j : Print Current Time");
  Serial.println("v : Set Date and Time");
  Serial.println("P : Set Speed of Capture");
  Serial.println("DoneMenus");
  StatusAllGood();
  while(  Serial.available() == 0 && !ButtonPushed) {
    ButtonPushed = !digitalRead(buttonPin);
  }
  if(ButtonPushed){
    if(!IMUsInitialized && !IMUsCalibrated){
      incomingByte = 105; //initialize i
    }else 
    if(IMUsInitialized && !IMUsCalibrated){
      incomingByte = 99; //calibrate c
    } else {
      incomingByte = 114; //read data....
    }
  }else{
    incomingByte = Serial.read();
  }
  Busy();
  
  // keyboard 't' is 116 decimal
  if (incomingByte == 116)
  {    
    
    TakeNumber = TakeNumber + 1;
    File uselessFile;
      RunTPose(uselessFile);
  } else
  // keyboard 'v' is 118 decimal
  if (incomingByte == 118)
  {
  GetTimeFromUserAndSet();
  } else
  // keyboard 'p' is 112 decimal
  if (incomingByte == 112)
  {
  CaptureDelay = SetSpeed(CaptureDelay);
  } else
  // keyboard 'c' is 99 decimal
  if (incomingByte == 99)
  {    
    if(IMUsInitialized){
      while(!ReadLineCalData("Cal Status:") && (Serial.available() == 0)){
        Busy();
        delay(BNO055_SAMPLERATE_DELAY_MS);
      }
      IMUsCalibrated = true;
      File emptyFile;
      //have user walk around for several seconds
      PrintLCDLine1("Pace Back&Forth");
      //Current Start Time in tick counts
      StartTime = millis();
      CurrentTime = 0;
      String TimeString = "";
      int WalkTimeSeconds = 30;
      while(CurrentTime < WalkTimeSeconds*1000){
        TimeString = String((float(WalkTimeSeconds) - (float(CurrentTime)/1000)),1);
        PrintLCDLine2("Done In:" + TimeString);
        Serial.println("Walk Time" + TimeString);
        CurrentTime = millis() - StartTime;
        ReadLineOfData("CALPNT", emptyFile, CurrentTime);
        delay(100); 
      }
      Serial.println("Done Calibration Successful");
      PrintLCDLine1("Done Calibration");
      PrintLCDLine2("Button 2 Record");
      
     } else {
        StatusAllBad();
        Serial.println("You Must Initialize the Sensors Prior to Calibration");
        PrintLCDLine1("Cannot Cal.");
        PrintLCDLine2("Must Init 1st.");
        delay(2000); 
     }
   incomingByte = Serial.read();
  } else
  // keyboard 'r' is 114 decimal
  if (incomingByte == 114)
  {    
    if(IMUsInitialized && IMUsCalibrated){
      String filename = DataLoggingName();
      Serial.println("Creating File:" + filename);
      File dataFile = SD.open(filename, FILE_WRITE);

      //Run TPose
      RunTPose(dataFile);
      
      PrintLCDLine1("Recording 2 File");
      PrintLCDLine2(filename);
      //Current Start Time in tick counts
      StartTime = millis();
      
      //Printing Start Time..
      TimeLine = "STARTIME " + GetTime();
      Serial.println(TimeLine);
      if(dataFile){
        PrintLine2File(TimeLine,dataFile);
      }

      //main read loop
      ButtonPushed = false;
      while(Serial.available() == 0 && !ButtonPushed ) {
        //setting LED to blining red..
        Recording();
        //checking button to see if we stop.
        ButtonPushed = !digitalRead(buttonPin);
        
        CurrentTime = millis() - StartTime;
        ReadLineOfData("PNTSTART", dataFile, CurrentTime);
        delay(CaptureDelay);
      }
      PrintLCDLine1("Done:" + filename);
      PrintLCDLine2("Button 2 Record");
      if(dataFile){
        dataFile.close();
      }
        StatusAllBad();
        delay(1000); 
    }else {
      StatusAllBad();
      Serial.println("You Must Initialize and Calibrate ALL of the Sensors Prior to Calibration");
      delay(2000); 
    }
    incomingByte = Serial.read();
  } else 
  if (incomingByte == 100)
  {
    sdCardPresentandIntialized = DetectAndDisplaySDCardInfo();
  } else 
  if (incomingByte == 101)
  {
    enumerateI2CBus();
  } else 
  if (incomingByte == 106)
  {
    PrintLCDLine1("Current Time:");
    PrintLCDLine2(GetTime());
    Serial.println(GetTime());
  } else 
  if (incomingByte == 115)
  {
    setMuxToPort();
  }else 
  if (incomingByte == 105)
  {
    InitAllIMUs();
    IMUsInitialized = true;
    Serial.println("IMUs Initialized.");
  } else
  if (incomingByte == 113){
      Serial.println("QuatMode Mode Enabled.");
      QuatMode = true;
  }else
  if (incomingByte == 119){
      Serial.println("Euler Mode Enabled.");
      QuatMode = false;
  }else
  {   
    // say what you got:
    Serial.print("I didn't understand the char I received with value: ");
    Serial.println(incomingByte, DEC);
  }
}

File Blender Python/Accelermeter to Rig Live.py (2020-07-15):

bl_info = {
    "name": "KeeCap IMU Tools",
    "description": "Tools for live capture and read in of Motion Capture Suit",
    "author": "Nick Keeline",
    "version": (1, 4, 0),
    "blender": (2, 83, 0),
    "location": "3D View > Tools",
    "warning": "", # used for warning icon and text in addons panel
    "wiki_url": "",
    "tracker_url": "",
    "category": "Motion Capture"
}

import sys
#this must point to a pyserial install dir for the OS (makes it work with Blender version currently running)
sys.path.append("C:\\Users\\Nick\\AppData\\Local\\Programs\\Python\\Python35\\Lib\\site-packages")
import bpy
import math

from bpy.props import (StringProperty,
                       BoolProperty,
                       IntProperty,
                       FloatProperty,
                       EnumProperty,
                       PointerProperty,
                       )
from bpy.types import (Panel,
                       Operator,
                       PropertyGroup,
                       )
import mathutils
import serial
import time
import math

ser = serial.Serial()

class Sensor(object):
    """This is a sensor object that is used in Python:

    Attributes:
        name: the Name of the Sensor (also the bone name it get's mapped to
        TPoseAngle: A Quaternion representing the angular position of the sensor in the TPose
        TranspositionToMatchBone: A Quat Representing Rotation Necessary to cause motion of the sensor to move the bone inthe right dirention
    """

    def __init__(self, name):
        """Return a Customer object whose name is *name*.""" 
        self.TransposeMethod = "None"
        self.name = name
        self.bonename = name
        self.firstpoint = True
        self.invalidpoint = False
        self.hastwistbone = False
        self.twistbonename = ""
        #this is the world space edit position of the bone the sensor will be applied to.
        self.boneEditRotWS = mathutils.Quaternion((1,0,0,0))
        #this is the virtual sensor on the character
        self.boneSensorProxyPosWS = mathutils.Quaternion((1,0,0,0))
        self.bonecorrection = mathutils.Quaternion((1,0,0,0))
#        self.previous_point = mathutils.Euler((math.radians(0), math.radians(0.0), math.radians(0)), 'XYZ')

    def __GetFirstFloatFromString (self, string, prefix ):
        """Return Float found in the string after prefix and ending with ~.""" 
        stringAfterPrefix = string.split(prefix)[1]
        floatstring = stringAfterPrefix.split("~")[0]
        return float(floatstring)
    
    def set_TPoseAngle(self, TPose):
        """Set the TPose Position for the Sensor."""
        self.TPoseAngle = TPose.copy()
        
    def set_calibrated(self, calbool):
        """Boolean indicating Calibrated"""
        self.initialized = calbool
        
    def set_twistbonename(self, tbonename):
        """If Sensor applies to a bend and twist bone we set the name here."""
        self.hastwistbone = True
        self.twistbonename = tbonename
        
    def set_bonecorrection(self, bonecorrection):
        """Correction Quaternion to be applied to sensor."""
        self.bonecorrection = bonecorrection
    
    def set_Name(self, name):
        """Set the Sensor Name."""
        self.name = name
        
    def set_bonename(self, bonename):
        """Bone Name if other than Sensor name"""
        self.bonename = bonename
        
    def set_initialized(self, initbool):
        """Boolean indicating Initialized"""
        self.initialized = initbool
        
    def set_firstPoint(self, firstPointDone):
        """Boolean indicating First Point"""
        self.firstpoint = firstPointDone
        
    def set_PreviousPoint(self, QuatPrevious):
        """A Value to Store the Previous Point"""
        self.prevPoint = QuatPrevious
        
    def set_TranspositionMethod(self, Method):
        """Set the TPose Position for the Sensor."""
        self.TransposeMethod = Method

    def set_CurrentAngle(self, Angle):
        """Set the TPose Position for the Sensor."""
        self.CurrentAngle = Angle

    def set_OrientationAngle(self, TranspositionQuat):
        """Set the TPose Position for the Sensor."""
        self.OrientationAngle = TranspositionQuat.copy()

    def set_boneEditRotWS(self, boneEditRotWSQuat):
        """Set the TPose Position for the Sensor."""
        self.boneEditRotWS = boneEditRotWSQuat.copy()

    def set_boneSensorProxyPosWS(self, boneSensorProxyPosWSQuat):
        """Set the TPose Position for the Sensor."""
        self.boneSensorProxyPosWS = boneSensorProxyPosWSQuat.copy()

    def set_AngleFromLine(self, textLine):
        """Parses a Line String and stores to the object the Current Position"""
        TextSplitByName = textLine.split("~~" + self.name + "~")
        if(len(TextSplitByName) > 1):
            finalQuat = self.getQuatFromLine(TextSplitByName)
            self.set_CurrentAngle(finalQuat)
                    
            print("CurrentAngle for " + self.name + " set To:")
            print(self.CurrentAngle)
    
    def set_TPoseAngleFromLine(self, textLine):
        """Parses a Line String and stores to the object the TPose Position"""
        TextSplitByName = textLine.split("~~" + self.name + "~")
        if(len(TextSplitByName) > 1):
            finalQuat = self.getQuatFromLine(TextSplitByName)
            self.set_TPoseAngle(finalQuat)
                    
            print("TPoseAngle Set To:")
            print(self.TPoseAngle)
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
